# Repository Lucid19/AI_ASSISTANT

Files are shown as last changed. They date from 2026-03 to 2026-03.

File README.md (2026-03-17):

# AI ASSISTANT 🚀
Designed as an ESP32 based board for TTS (Text to Speech) and STT (Speech to Text) communicating with AI API through enabled WiFi. Set up with an Electret Condenser Microphone and 1W speaker with an amplified signal. This board is suitable for hobbyists and is capable of being hand soldered.

## 📋 Features
* ⚡ Input Voltage: 3.3V - 10V
* 🧩 MCU: ESP32-S3-WROOM (WiFi enabled)
* 📢 Speaker: 1W 8ohm impedance (SP-4005Y)
* 📏 Size: 95x65mm
* 🔌 USB-C charging and programming

## 🔌 Pinout
INTEGRATED
* | GPIO01 | Microphone-Amplifier Input | ADC
* | GPIO10 | DAC Audio Sync | I2S
* | GPIO11 | Digital Audio Output to DAC | I2S
* | GPIO12 | DAC Serial Clock | I2S
* | GPIO45 | Blue LED | GPIO
* | GPIO46 | Green LED | GPIO

USB DIFFERENTIALS
* | GPIO19 | Negative
* | GPIO20 | Positive

GENERAL 
* | RX | UART | Do not connect during firmware update |
* | TX | UART |
* | GPIO35 | SPI/GENERIC | I/O
* | GPIO36 | SPI/GENERIC | I/O
* | GPIO37 | SPI/GENERIC | I/O
* | GPIO38 | GENERIC/RGB | I/O
* | GPIO39 | JTAG (MTCK) | I/O
* | GPIO40 | JTAG (MTDO) | I/O 
* | GPIO41 | JTAG (MTDI) | I/O
* | GPIO42 | JTAG (MTMS) | I/O

(RTC Supported)
* | GPIO13 | Digital I/O, PWM, SPI/I2C/UART | I/O
* | GPIO14 | Digital I/O, PWM, SPI/I2C/UART | I/O
* | GPIO15 | Digital I/O, PWM, SPI/I2C/UART | I/O
* | GPIO16 | Digital I/O, PWM, SPI/I2C/UART | I/O
* | GPIO21 | Digital I/O, PWM, SPI/I2C/UART | I/O
  
* | A2-A9 | Analog sensing interface | Input |

Note: This board is NOT compatible with Octal PSRAM (R8) modules. Use Quad SPI (N4/N8/R2) versions only.

## 🛠 Setup & Usage
Programmable using Arduino IDE or VS Code + PlatformIO
To upload code:
1. Short the Boot Jumper
2. Press and release the Reset button (or toggle the power). The chip "looks" at GPIO 0, sees it is Low, and enters Download Mode.
3. Start the upload in your software (Arduino/PlatformIO).
4. Once finished, remove the jumper.
5. Press Reset again to run your code.

## 📦 Key Components
* ESP32-S3-WROOM
* TPC114S1-VR DAC Converter
* PAM8406DR Sound Amplifier
* CMA-4544PF-W Electret Condenser Microphone
* TPS77833 LDO Regulator
* USB-C 16-pin Connector

## estimated price (as of 14/03/26)
£13.60 (components) + £3.76-£6.78 (JLPCB)
= £17.36-£20.38 + shipping fees

---
*Created by Daumantas Dauksas - 2026*

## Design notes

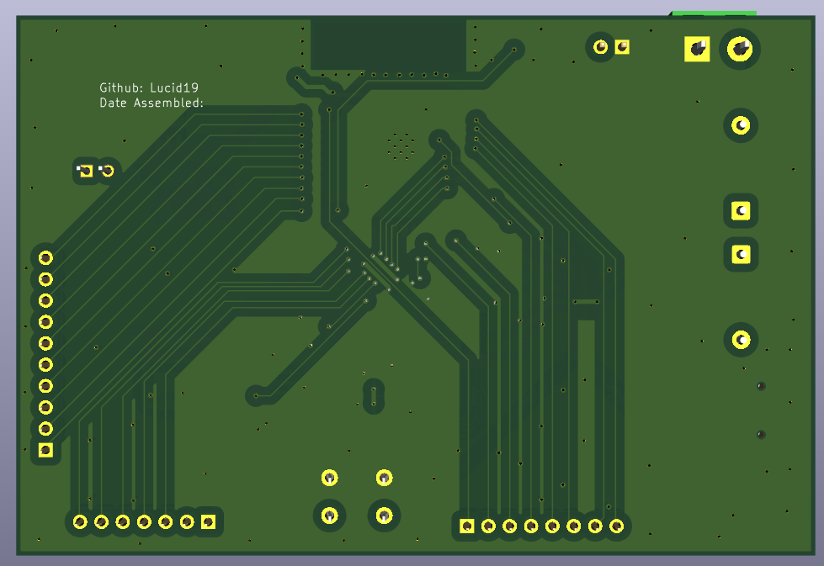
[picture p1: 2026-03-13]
Rendered Design/pcbback.png

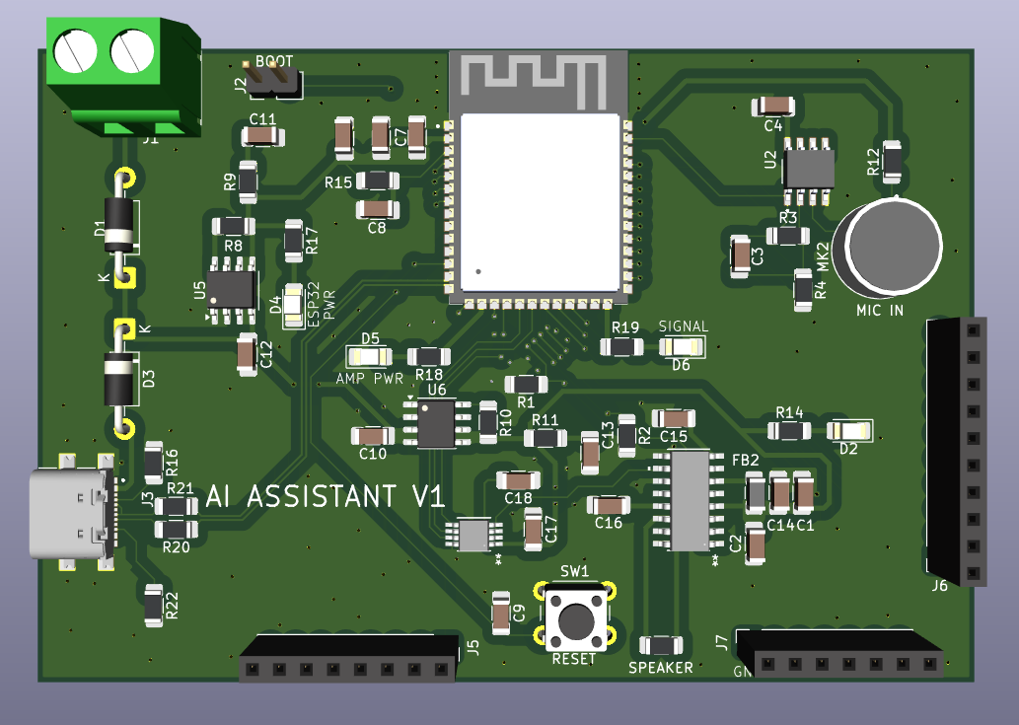
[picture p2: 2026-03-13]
Rendered Design/pcbforward.png

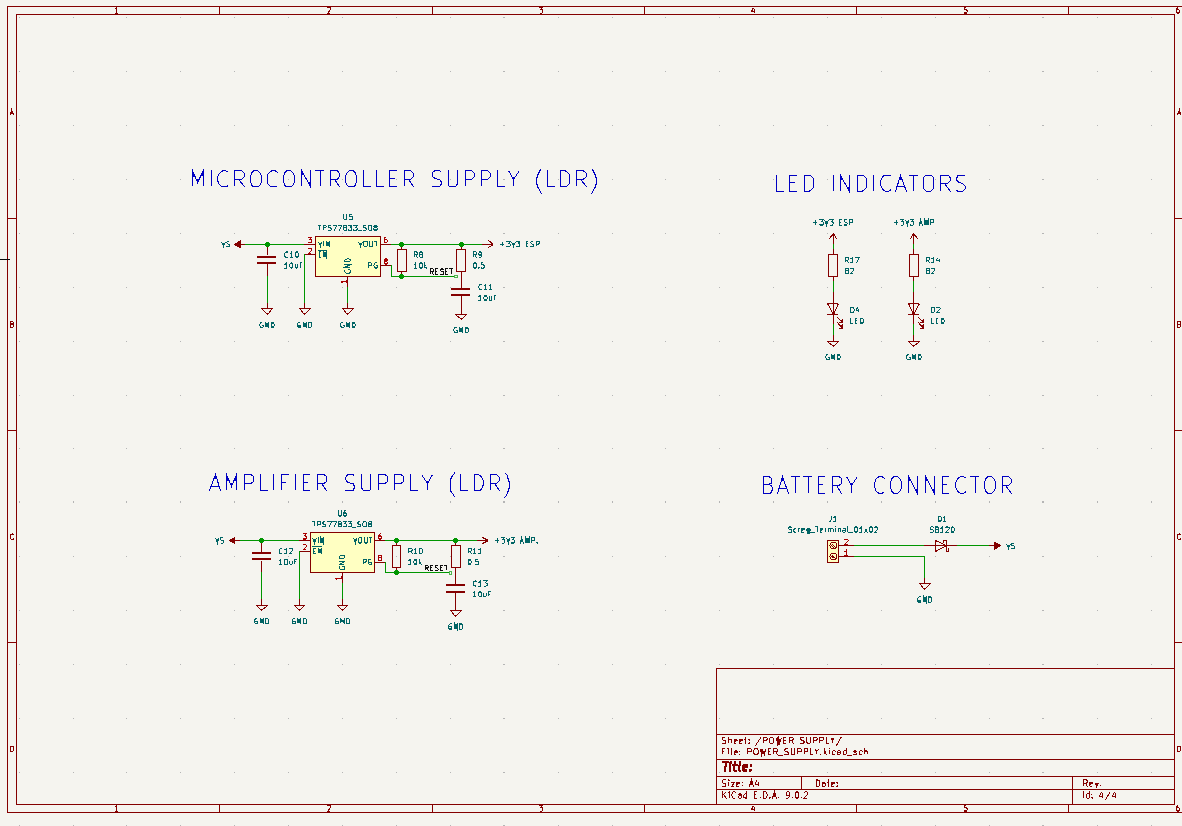
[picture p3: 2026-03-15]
Schematics/Power_Supply_schem.png

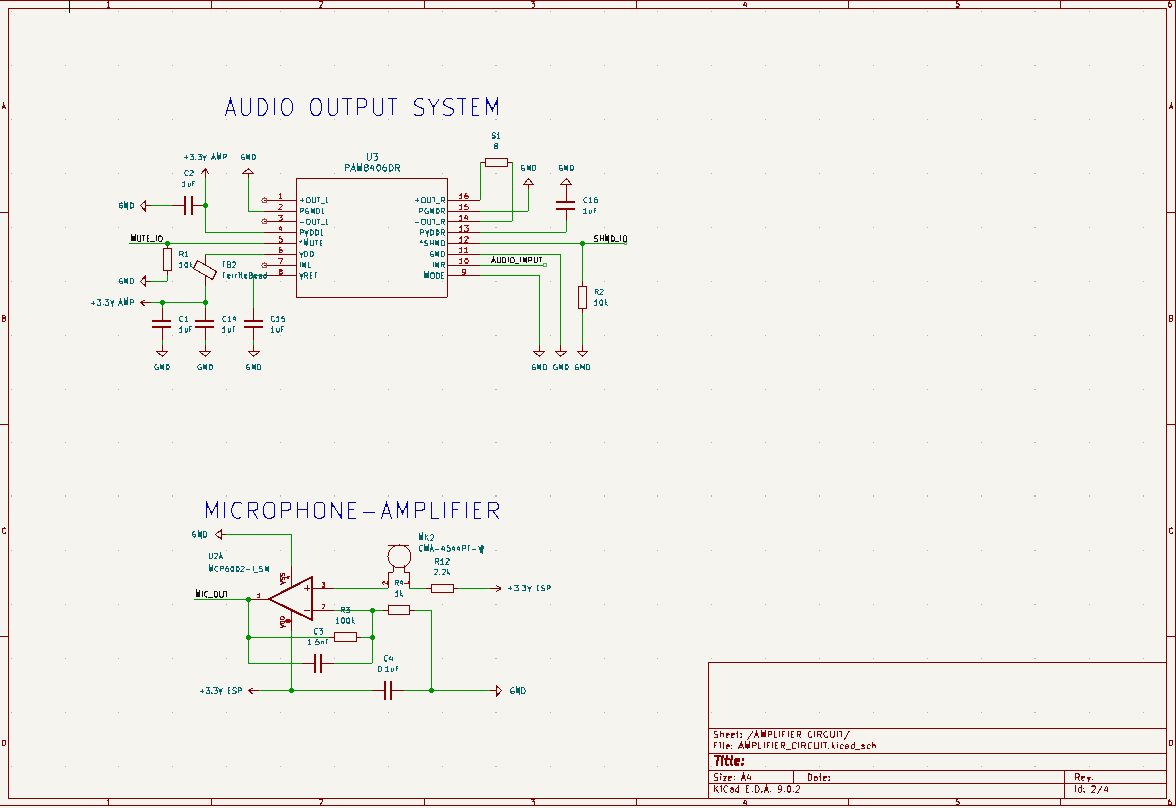
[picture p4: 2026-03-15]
Schematics/Audio_Amplifier_schem.png

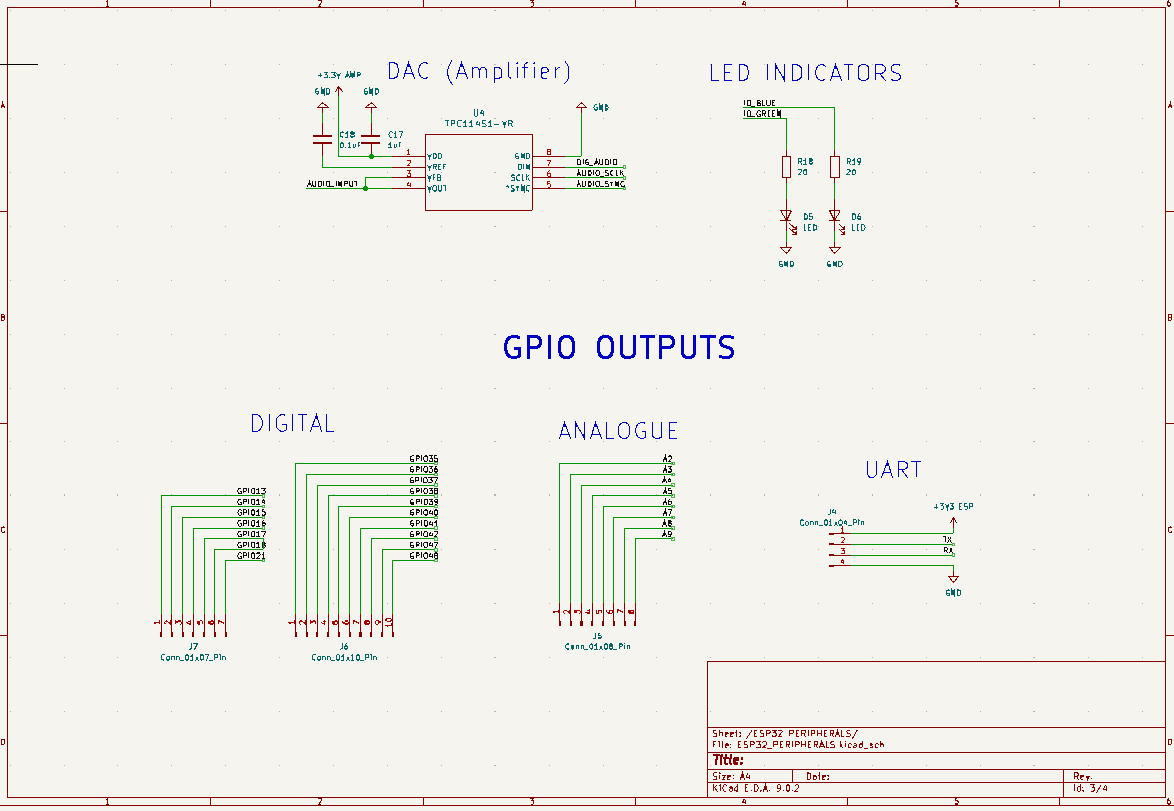
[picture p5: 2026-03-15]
Schematics/Peripheral_Schem.png

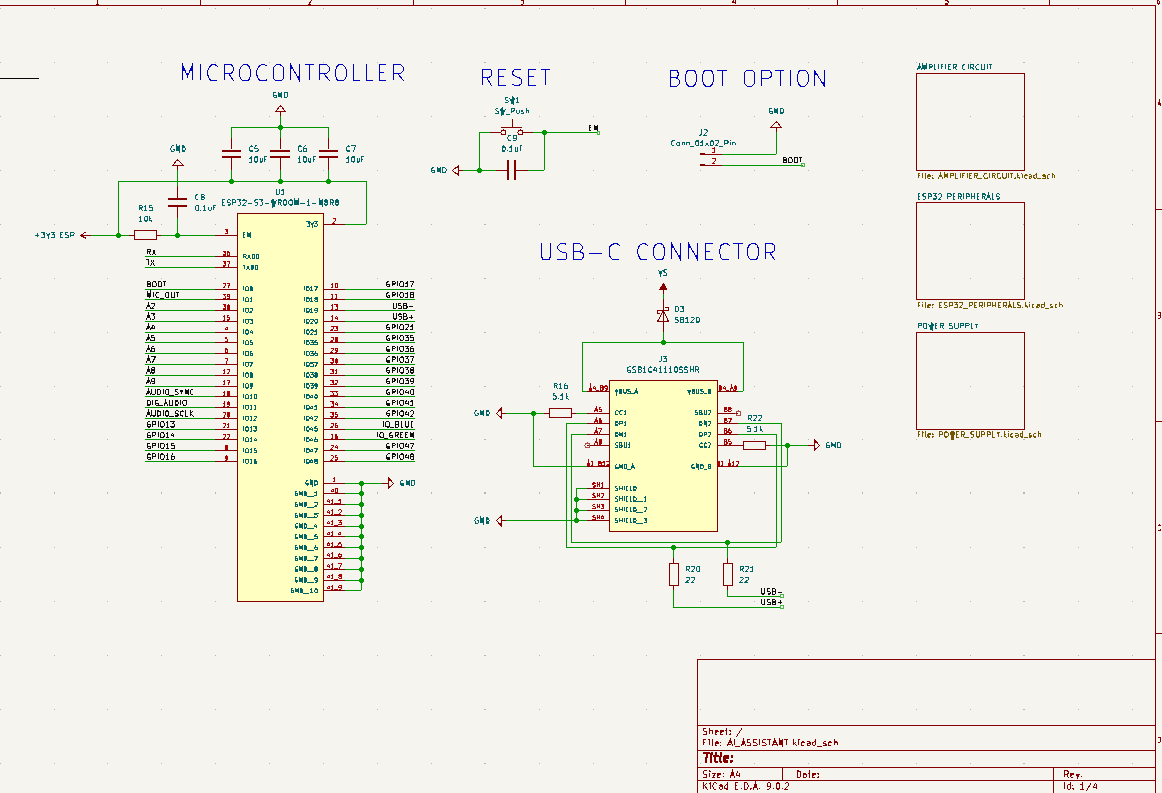
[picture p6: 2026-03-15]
Schematics/Microcontroller schem.png

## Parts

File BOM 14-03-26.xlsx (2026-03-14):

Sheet: BOM_DigiKey_Active_Stock
Reference | Value | Datasheet | Footprint | Product Number | Qty | DNP | Market Price (£) | DigiKey Part Number | DigiKey Unit Price (£) | DigiKey Total Price (£)
C1,C2,C14,C15,C16,C17 | 1uF | ~ | Capacitor_SMD:C_1206_3216Metric_Pad1.33x1.80mm_HandSolder | 1206B105K250JC | 6 |  | 0.57852 | 490-1046-1-ND | 0.08 | 0.48
C3 | 1.5nF | ~ | Capacitor_SMD:C_1206_3216Metric_Pad1.33x1.80mm_HandSolder | 1206B152K102DC | 1 |  | 0.10765 | 490-1025-1-ND | 0.1 | 0.1
C4,C8,C9,C18 | 0.1uF | ~ | Capacitor_SMD:C_1206_3216Metric_Pad1.33x1.80mm_HandSolder | 1206B104K101CC | 4 |  | 0.23296 | 490-1533-1-ND | 0.05 | 0.2
C5,C6,C7,C10,C11,C12,C13 | 10uF | ~ | Capacitor_SMD:C_1206_3216Metric_Pad1.33x1.80mm_HandSolder | 1206B106K250PB | 7 |  | 1.98499 | 490-1065-1-ND | 0.15 | 1.05
D1,D3 | SB120-E3/54 | http://www.diodes.com/_files/datasheets/ds23022.pdf | Diode_THT:D_DO-41_SOD81_P10.16mm_Horizontal | SMD14HT-TP | 2 |  | 0.18 | 112-SB120-E3/54CT-ND | 0.22 | 0.44
D2,D4,D5,D6 | LED | ~ | LED_SMD:LED_1206_3216Metric_Pad1.42x1.75mm_HandSolder |  | 4 |  | 0.04116 | 732-4982-1-ND | 0.12 | 0.48
FB2 | FerriteBead | ~ | Inductor_SMD:L_1206_3216Metric_Pad1.42x1.75mm_HandSolder | HI1206T500R-10 | 1 |  | 0.08 | 732-1563-1-ND | 0.1 | 0.1
J1 | Screw_Terminal_01x02 | ~ | TerminalBlock:TerminalBlock_bornier-2_P5.08mm |  | 1 |  | 0.19 | 277-1247-ND | 0.45 | 0.45
J2 | Conn_01x02_Pin | ~ | Connector_PinHeader_2.54mm:PinHeader_1x02_P2.54mm_Vertical |  | 1 |  | 0.19 | S1011EC-02-ND | 0.2 | 0.2
J3 | GSB1C41110SSHR |  | GSB1C41110SSHR:AMPHENOL_GSB1C41110SSHR |  | 1 |  | 0.09642 | GSB1C41110SSHR-ND | 0.55 | 0.55
J4 | Conn_01x04_Pin | ~ | Connector_PinSocket_2.54mm:PinSocket_1x04_P2.54mm_Vertical |  | 1 |  | 0.09642 | S1011EC-04-ND | 0.25 | 0.25
J5 | Conn_01x08_Pin | ~ | Connector_PinSocket_2.54mm:PinSocket_1x08_P2.54mm_Vertical |  | 1 |  | 0.09642 | S1011EC-08-ND | 0.35 | 0.35
J6 | Conn_01x10_Pin | ~ | Connector_PinSocket_2.54mm:PinSocket_1x10_P2.54mm_Vertical |  | 1 |  | 0.09642 | S1011EC-10-ND | 0.4 | 0.4
J7 | Conn_01x07_Pin | ~ | Connector_PinSocket_2.54mm:PinSocket_1x07_P2.54mm_Vertical |  | 1 |  | 0.09642 | S1011EC-07-ND | 0.32 | 0.32
MK2 | CMA-4544PF-W |  | CMA-4544PF-W:MIC_CMA-4544PF-W |  | 1 |  | 0.09642 | 102-AOM-4544P-2-R-ND | 0.85 | 0.85
R1,R2,R8,R10,R15 | 10k | ~ | Resistor_SMD:R_1206_3216Metric_Pad1.30x1.75mm_HandSolder |  | 5 |  | 0.4821 | 311-10KARCT-ND | 0.02 | 0.1
R3 | 100k | ~ | Resistor_SMD:R_1206_3216Metric_Pad1.30x1.75mm_HandSolder |  | 1 |  | 0.09642 | 311-100KARCT-ND | 0.02 | 0.02
R4 | 1k | ~ | Resistor_SMD:R_1206_3216Metric_Pad1.30x1.75mm_HandSolder |  | 1 |  | 0.09642 | 311-1.0KARCT-ND | 0.02 | 0.02
R9,R11 | 0.5 | ~ | Resistor_SMD:R_1206_3216Metric_Pad1.30x1.75mm_HandSolder |  | 2 |  | 0.19284 | 311-0.50ERCT-ND | 0.03 | 0.06
R12 | 2.2k | ~ | Resistor_SMD:R_1206_3216Metric_Pad1.30x1.75mm_HandSolder |  | 1 |  | 0.09642 | 311-2.2KARCT-ND | 0.02 | 0.02
R14,R17 | 82 | ~ | Resistor_SMD:R_1206_3216Metric_Pad1.30x1.75mm_HandSolder |  | 2 |  | 0.19284 | 311-82ARCT-ND | 0.02 | 0.04
R16,R22 | 5.1k | ~ | Resistor_SMD:R_1206_3216Metric_Pad1.30x1.75mm_HandSolder |  | 2 |  | 0.19284 | 311-5.1KARCT-ND | 0.02 | 0.04
R18,R19 | 20 | ~ | Resistor_SMD:R_1206_3216Metric_Pad1.30x1.75mm_HandSolder |  | 2 |  | 0.19284 | 311-20ARCT-ND | 0.02 | 0.04
R20,R21 | 22 | ~ | Resistor_SMD:R_1206_3216Metric_Pad1.30x1.75mm_HandSolder |  | 2 |  | 0.19284 | 311-22ARCT-ND | 0.02 | 0.04
S1 | 8 | ~ | Resistor_SMD:R_1206_3216Metric_Pad1.30x1.75mm_HandSolder |  | 1 |  | 0.09642 | 311-8.0ARCT-ND | 0.02 | 0.02
SW1 | SW_Push | ~ | Button_Switch_THT:SW_PUSH_6mm |  | 1 |  | 0.09642 | EG4356-ND | 0.18 | 0.18
U1 | ESP32-S3-WROOM-1-N8 |  | ESP32-S3-WROOM-1-N8R8:XCVR_ESP32S3WROOM1N8R8 |  | 1 |  | 0.09642 | 3210-ESP32-S3-WROOM-1-N8CT-ND | 2.8 | 2.8
U2 | MCP6002-I_SN |  | MCP6002_I_SN:SOIC127P600X175-8N |  | 1 |  | 0.09642 | MCP6002-I/SN-ND | 0.45 | 0.45
U3 | PAM8406DR | PAM8406DR | PAM8406DR:SO-16_PAM8406_DIO-M |  | 1 |  | 0.09642 | PAM8406DR-ND | 0.6 | 0.6
U4 | TPC114S1-VR | TPC114S1-VR | TPC114S1_VR:MSOP-8_TPK |  | 1 |  | 0.09642 | MCP6002T-I/MSCT-ND | 0.45 | 0.45
U5,U6 | TPS77833_SO8 | http://www.ti.com/lit/ds/symlink/tps777.pdf | Package_SO:SOIC-8_3.9x4.9mm_P1.27mm |  | 2 |  | 0.19284 | 296-13583-1-ND | 1.25 | 2.5
 |  |  |  |  |  |  |  |  |  | Total Market Price (£)
 |  |  |  |  |  |  |  |  |  | 13.6

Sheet: BOM
Reference | Value | Datasheet | Footprint | Product Number | Qty | DNP | Market Price (£)
C1,C2,C14,C15,C16,C17 | 1uF | ~ | Capacitor_SMD:C_1206_3216Metric_Pad1.33x1.80mm_HandSolder | 1206B105K250JC | 6 |  | 0.57852
C3 | 1.5nF | ~ | Capacitor_SMD:C_1206_3216Metric_Pad1.33x1.80mm_HandSolder | 1206B152K102DC | 1 |  | 0.10765
C4,C8,C9,C18 | 0.1uF | ~ | Capacitor_SMD:C_1206_3216Metric_Pad1.33x1.80mm_HandSolder | 1206B104K101CC | 4 |  | 0.23296
C5,C6,C7,C10,C11,C12,C13 | 10uF | ~ | Capacitor_SMD:C_1206_3216Metric_Pad1.33x1.80mm_HandSolder | 1206B106K250PB | 7 |  | 1.98499
D1,D3 | SB120 | http://www.diodes.com/_files/datasheets/ds23022.pdf | Diode_THT:D_DO-41_SOD81_P10.16mm_Horizontal | SMD14HT-TP | 2 |  | 0.18
D2,D4,D5,D6 | LED | ~ | LED_SMD:LED_1206_3216Metric_Pad1.42x1.75mm_HandSolder |  | 4 |  | 0.04116
FB2 | FerriteBead | ~ | Inductor_SMD:L_1206_3216Metric_Pad1.42x1.75mm_HandSolder | HI1206T500R-10 | 1 |  | 0.08
J1 | Screw_Terminal_01x02 | ~ | TerminalBlock:TerminalBlock_bornier-2_P5.08mm | 277-1247-ND | 1 |  | 0.45
J2 | Conn_01x02_Pin | ~ | Connector_PinHeader_2.54mm:PinHeader_1x02_P2.54mm_Vertical |  | 1 |  | 0.19
J3 | GSB1C41110SSHR |  | GSB1C41110SSHR:AMPHENOL_GSB1C41110SSHR |  | 1 |  | 0.09642
J4 | Conn_01x04_Pin | ~ | Connector_PinSocket_2.54mm:PinSocket_1x04_P2.54mm_Vertical |  | 1 |  | 0.09642
J5 | Conn_01x08_Pin | ~ | Connector_PinSocket_2.54mm:PinSocket_1x08_P2.54mm_Vertical |  | 1 |  | 0.09642
J6 | Conn_01x10_Pin | ~ | Connector_PinSocket_2.54mm:PinSocket_1x10_P2.54mm_Vertical |  | 1 |  | 0.09642
J7 | Conn_01x07_Pin | ~ | Connector_PinSocket_2.54mm:PinSocket_1x07_P2.54mm_Vertical |  | 1 |  | 0.09642
MK2 | CMA-4544PF-W |  | CMA-4544PF-W:MIC_CMA-4544PF-W |  | 1 |  | 0.09642
R1,R2,R8,R10,R15 | 10k | ~ | Resistor_SMD:R_1206_3216Metric_Pad1.30x1.75mm_HandSolder |  | 5 |  | 0.4821
R3 | 100k | ~ | Resistor_SMD:R_1206_3216Metric_Pad1.30x1.75mm_HandSolder |  | 1 |  | 0.09642
R4 | 1k | ~ | Resistor_SMD:R_1206_3216Metric_Pad1.30x1.75mm_HandSolder |  | 1 |  | 0.09642
R9,R11 | 0.5 | ~ | Resistor_SMD:R_1206_3216Metric_Pad1.30x1.75mm_HandSolder |  | 2 |  | 0.19284
R12 | 2.2k | ~ | Resistor_SMD:R_1206_3216Metric_Pad1.30x1.75mm_HandSolder |  | 1 |  | 0.09642
R14,R17 | 82 | ~ | Resistor_SMD:R_1206_3216Metric_Pad1.30x1.75mm_HandSolder |  | 2 |  | 0.19284
R16,R22 | 5.1k | ~ | Resistor_SMD:R_1206_3216Metric_Pad1.30x1.75mm_HandSolder |  | 2 |  | 0.19284
R18,R19 | 20 | ~ | Resistor_SMD:R_1206_3216Metric_Pad1.30x1.75mm_HandSolder |  | 2 |  | 0.19284
R20,R21 | 22 | ~ | Resistor_SMD:R_1206_3216Metric_Pad1.30x1.75mm_HandSolder |  | 2 |  | 0.19284
S1 | 8 | ~ | Resistor_SMD:R_1206_3216Metric_Pad1.30x1.75mm_HandSolder |  | 1 |  | 0.09642
SW1 | SW_Push | ~ | Button_Switch_THT:SW_PUSH_6mm |  | 1 |  | 0.09642
U1 | ESP32-S3-WROOM-1-N8 |  | ESP32-S3-WROOM-1-N8R8:XCVR_ESP32S3WROOM1N8R8 |  | 1 |  | 0.09642
U2 | MCP6002-I_SN |  | MCP6002_I_SN:SOIC127P600X175-8N |  | 1 |  | 0.09642
U3 | PAM8406DR | PAM8406DR | PAM8406DR:SO-16_PAM8406_DIO-M |  | 1 |  | 0.09642
U4 | TPC114S1-VR | TPC114S1-VR | TPC114S1_VR:MSOP-8_TPK |  | 1 |  | 0.09642
U5,U6 | TPS77833_SO8 | http://www.ti.com/lit/ds/symlink/tps777.pdf | Package_SO:SOIC-8_3.9x4.9mm_P1.27mm |  | 2 |  | 0.19284
 |  |  |  |  |  |  | TOTAL (£)
 |  |  |  |  |  |  | 6.93072

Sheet: Sheet 1
"""Reference"",""Value"",""Datasheet"",""Footprint"",""Qty"",""DNP"""
"C1,C2,C14,C15,C16,C17","1uF","~","Capacitor_SMD:C_1206_3216Metric_Pad1.33x1.80mm_HandSolder","6",""
"C3","1.5nF","~","Capacitor_SMD:C_1206_3216Metric_Pad1.33x1.80mm_HandSolder","1",""
"C4,C8,C9,C18","0.1uF","~","Capacitor_SMD:C_1206_3216Metric_Pad1.33x1.80mm_HandSolder","4",""
"C5,C6,C7,C10,C11,C12,C13","10uF","~","Capacitor_SMD:C_1206_3216Metric_Pad1.33x1.80mm_HandSolder","7",""
"D1,D3","SB120","http://www.diodes.com/_files/datasheets/ds23022.pdf","Diode_THT:D_DO-41_SOD81_P10.16mm_Horizontal","2",""
"D2,D4,D5,D6","LED","~","LED_SMD:LED_1206_3216Metric_Pad1.42x1.75mm_HandSolder","4",""
"FB2","FerriteBead","~","Inductor_SMD:L_1206_3216Metric_Pad1.42x1.75mm_HandSolder","1",""
"J1","Screw_Terminal_01x02","~","TerminalBlock:TerminalBlock_bornier-2_P5.08mm","1",""
"J2","Conn_01x02_Pin","~","Connector_PinHeader_2.54mm:PinHeader_1x02_P2.54mm_Vertical","1",""
"J3","GSB1C41110SSHR","","GSB1C41110SSHR:AMPHENOL_GSB1C41110SSHR","1",""
"J4","Conn_01x04_Pin","~","Connector_PinSocket_2.54mm:PinSocket_1x04_P2.54mm_Vertical","1",""
"J5","Conn_01x08_Pin","~","Connector_PinSocket_2.54mm:PinSocket_1x08_P2.54mm_Vertical","1",""
"J6","Conn_01x10_Pin","~","Connector_PinSocket_2.54mm:PinSocket_1x10_P2.54mm_Vertical","1",""
"J7","Conn_01x07_Pin","~","Connector_PinSocket_2.54mm:PinSocket_1x07_P2.54mm_Vertical","1",""
"MK2","CMA-4544PF-W","","CMA-4544PF-W:MIC_CMA-4544PF-W","1",""
"R1,R2,R8,R10,R15","10k","~","Resistor_SMD:R_1206_3216Metric_Pad1.30x1.75mm_HandSolder","5",""
"R3","100k","~","Resistor_SMD:R_1206_3216Metric_Pad1.30x1.75mm_HandSolder","1",""
"R4","1k","~","Resistor_SMD:R_1206_3216Metric_Pad1.30x1.75mm_HandSolder","1",""
"R9,R11","0.5","~","Resistor_SMD:R_1206_3216Metric_Pad1.30x1.75mm_HandSolder","2",""
"R12","2.2k","~","Resistor_SMD:R_1206_3216Metric_Pad1.30x1.75mm_HandSolder","1",""
"R14,R17","82","~","Resistor_SMD:R_1206_3216Metric_Pad1.30x1.75mm_HandSolder","2",""
"R16,R22","5.1k","~","Resistor_SMD:R_1206_3216Metric_Pad1.30x1.75mm_HandSolder","2",""
"R18,R19","20","~","Resistor_SMD:R_1206_3216Metric_Pad1.30x1.75mm_HandSolder","2",""
"R20,R21","22","~","Resistor_SMD:R_1206_3216Metric_Pad1.30x1.75mm_HandSolder","2",""
"S1","8","~","Resistor_SMD:R_1206_3216Metric_Pad1.30x1.75mm_HandSolder","1",""
"SW1","SW_Push","~","Button_Switch_THT:SW_PUSH_6mm","1",""
"U1","ESP32-S3-WROOM-1-N8R8","","ESP32-S3-WROOM-1-N8R8:XCVR_ESP32S3WROOM1N8R8","1",""
"U2","MCP6002-I_SN","","MCP6002_I_SN:SOIC127P600X175-8N","1",""
"U3","PAM8406DR","PAM8406DR","PAM8406DR:SO-16_PAM8406_DIO-M","1",""
"U4","TPC114S1-VR","TPC114S1-VR","TPC114S1_VR:MSOP-8_TPK","1",""
"U5,U6","TPS77833_SO8","http://www.ti.com/lit/ds/symlink/tps777.pdf","Package_SO:SOIC-8_3.9x4.9mm_P1.27mm","2",""

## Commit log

2026-03-14 Enhance README with board details and setup instructions
    Updated the README to provide a detailed description of the board's functionality, features, pinout, setup instructions, and key components.
2026-03-14 Enhance README with hobbyist suitability details
    Added a note about hobbyist suitability and hand soldering capabilities.
2026-03-15 Create Schematics
